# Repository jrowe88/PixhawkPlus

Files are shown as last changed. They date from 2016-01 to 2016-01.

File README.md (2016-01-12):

# Pixhawk Plus #
The [Pixhawk](https://pixhawk.org/choice) and [PX4](http://px4.io/) flight stack are workhorses in DIY drone world.  

Often paired with an OpenTX receiver such as the FrSky, you have a powerful combination.

Pixhawk Plus aims to make better use of this great combination by providing an easy-to-use, modular set of add-ons:

1. Telemetry pass-through from the Pixhawk to your OpenTX receiver.
2. Robust LED indicator lights--multiple arms, multiple programs.
3. Per-cell LIPO voltage monitoring.

## Getting Started ##
- Get the code
- Get the hardware
- Assemble and go!

[See the Wiki for complete instructions](http://#)

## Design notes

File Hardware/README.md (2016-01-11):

# Pixhawk Plus Circuit Boards #
This folder contains Eagle files for corresponding hardware. These boards are not required, but make the packaging neater than soldering a bunch of wires to a Teensy 3.2.

You can order your own, simply wire to the Teensy, or come up with your own creation.  See the Wiki for more options and ideas.

##Primary Board:##
This code and "backpack" are designed to work with [Teensy 3.2](https://www.pjrc.com/store/teensy32.html) development board.  Probably would world with Feather, or Arduino Mini, but I haven't tried that.

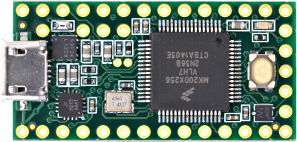
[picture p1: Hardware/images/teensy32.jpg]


##Quadcopter Backpack:##

- Order from [OSHPark.com](https://oshpark.com/shared_projects/TG4BuGQ4) or [contact me](mailto:jim.rowe@gmail.com) for spare boards I may be willing to send you for nominal fee.
- BOM Parts for the Backpack: [From DigiKey](http://www.digikey.com/short/tvfnt3)


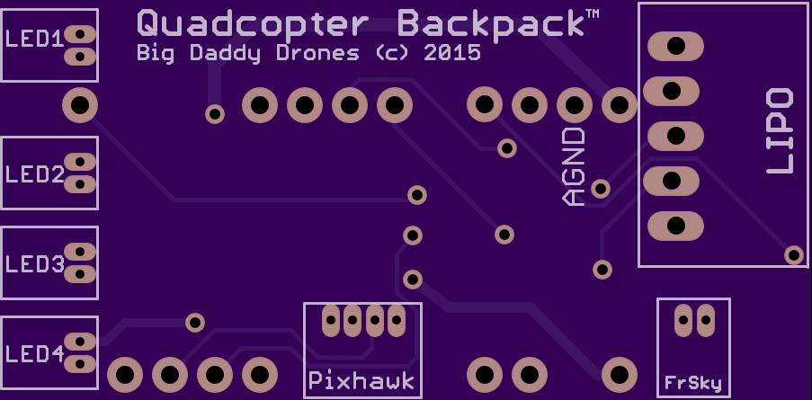
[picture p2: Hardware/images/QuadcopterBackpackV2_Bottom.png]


##LED Leg:##

- Order from [OSHPark.com](https://oshpark.com/shared_projects/HVTKyU7v) or [contact me](mailto:jim.rowe@gmail.com) for spare boards I may be willing to send you for nominal fee.
- You can also use Adafruit NeoPixel or other strips of WS2812b RGB LED lights found from many distributors.

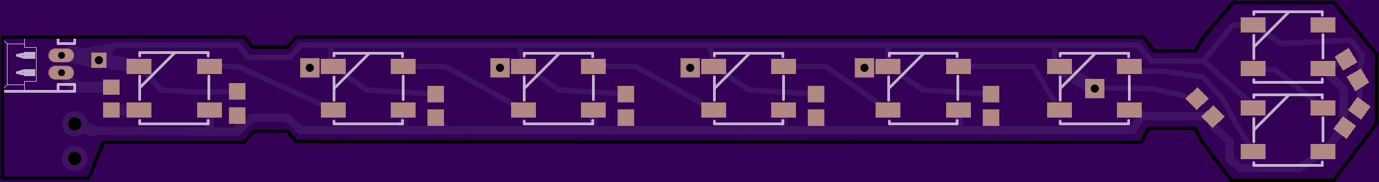
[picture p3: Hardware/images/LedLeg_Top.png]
<a href="https://oshpark.com/shared_projects/HVTKyU7v"><br/></a>
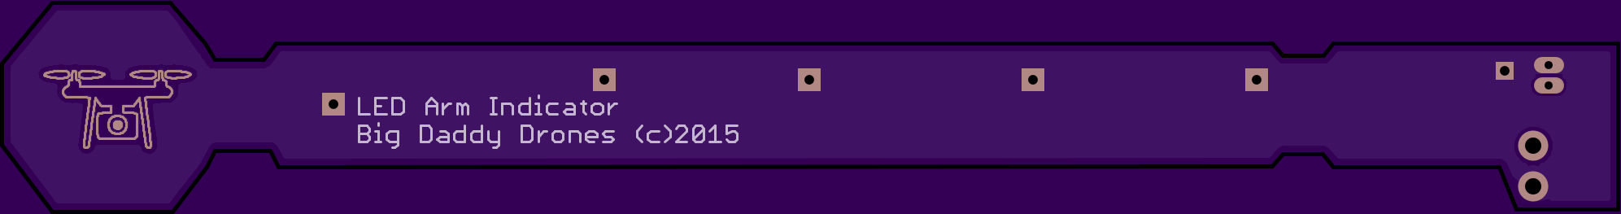
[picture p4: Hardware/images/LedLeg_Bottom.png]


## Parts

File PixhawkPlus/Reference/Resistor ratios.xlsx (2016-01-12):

Voltage Divider Calculator
 |  |  |  |  |  |  |  |  | 4.2 | max per-cell voltage
 | Vin = Vout * H |  |  |  |  |  |  |  | 13 | analog resolution bits
 | H = R2 / (R2 + R1) |  |  |  |  |  |  |  | 8192 | bits sampled
 |  |  |  |  |  |  |  |  | min wattage |  | Examples
Cell | Vin | R1 | R2 | H | Vout | OK? | Ref. Voltage | counts / V | size R1 | size R2 | counts | volts
1 | 4.2 | 993 | 3320 | 0.76977 | 3.233 | Yes | 3.320 | 1899.14213 | 1/10 | 1/10 | 552 | 0.290657551
2 | 8.4 | 1960 | 1240 | 0.38750 | 3.255 | Yes | 3.320 | 956.02786 | 1/10 | 1/10 | 202 | 0.2112909133
3 | 12.6 | 3600 | 1240 | 0.25620 | 3.228 | Yes | 3.320 | 632.08454 | 1/10 | 1/4 | 2662 | 4.21146199
4 | 16.8 | 9090 | 2210 | 0.19558 | 3.286 | Yes | 3.320 | 482.51706 | 1/10 | 1/4 | 8046 | 16.6750581
5 | 21.0 | 6800 | 1240 | 0.15423 | 3.239 | Yes | 3.320 | 380.50860 | 1/10 | 1/2 | 7500 | 19.71046113
6 | 25.2 | 11000 | 1600 | 0.12698 | 3.200 | Yes | 3.320 | 313.29126 | 1/10 | 1/2 | 7000 | 22.34342571
 |  | ^== choose R1 and R2 values to create appropriate ranged Vout
 |  |  |  |  | ^== must be lower than the max reference voltage
 |  |  |  |  |  |  |  |  | ^== choose R1 and R2 that are at least the min wattage listed
Resistor Wattages
0 | 0
0.1 | 1/10
0.125 | 1/8
0.25 | 1/4
0.5 | 1/2

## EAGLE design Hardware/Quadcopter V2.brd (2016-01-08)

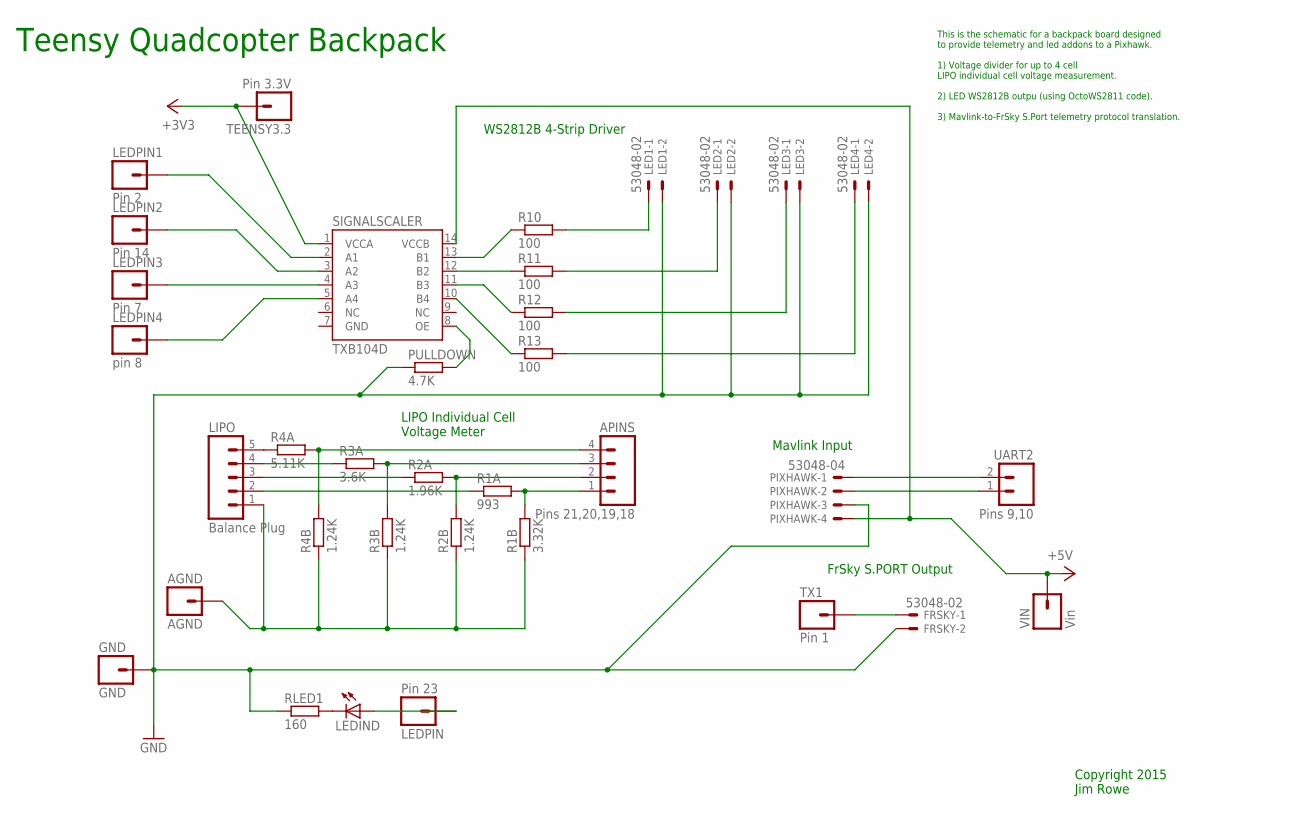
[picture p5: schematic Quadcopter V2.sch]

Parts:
AGND: AGND; 1X01_NO_SILK
APINS: Pins 21,20,19,18; 1X04_NO_SILK_ALL_ROUND
FRSKY: 53048-02
GND: GND; 1X01_NO_SILK
LED1, LED2, LED3, LED4: 53048-02
LEDIND: LEDCHIPLED_0603; CHIPLED_0603
LEDPIN: Pin 23; 1X01_NO_SILK
LEDPIN1: Pin 2; 1X01_NO_SILK
LEDPIN2: Pin 14; 1X01_NO_SILK
LEDPIN3: Pin 7; 1X01_NO_SILK
LEDPIN4: pin 8; 1X01_NO_SILK
LIPO: Balance Plug; 1X05_LOCK_LONGPADS
PIXHAWK: 53048-04
PULLDOWN: 4.7K; R0805
R1A: 993; R0805
R1B: 3.32K; R0805
R2A: 1.96K; R0805
R2B, R3B, R4B: 1.24K; R0805
R3A: 3.6K; R0805
R4A: 5.11K; R0805
R10, R11, R12, R13: 100; R0805
RLED1: 160; R0603
SIGNALSCALER: TXB104D; SOIC(D)-14
TEENSY3.3: Pin 3.3V; 1X01_NO_SILK
TX1: Pin 1; 1X01_NO_SILK
UART2: Pins 9,10; 1X02_NO_SILK
VIN: Vin; 1X01_NO_SILK

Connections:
+3V3: SIGNALSCALER.1 (VCCA), TEENSY3.3.1
+5V: PIXHAWK.4, SIGNALSCALER.14 (VCCB), VIN.1
GND: FRSKY.2, GND.1, LED1.2, LED2.2, LED3.2, LED4.2, PIXHAWK.3, PULLDOWN.1, RLED1.1, SIGNALSCALER.7 (GND)
unnamed: R10.1, SIGNALSCALER.13 (B1)
unnamed: R11.1, SIGNALSCALER.12 (B2)
unnamed: R12.1, SIGNALSCALER.11 (B3)
unnamed: R13.1, SIGNALSCALER.10 (B4)
unnamed: APINS.4, R4A.2, R4B.2
unnamed: APINS.3, R3A.2, R3B.2
unnamed: APINS.2, R2A.2, R2B.2
unnamed: LIPO.5, R4A.1
unnamed: LIPO.4, R3A.1
unnamed: LIPO.3, R2A.1
unnamed: LIPO.2, R1A.1
unnamed: LEDPIN1.1, SIGNALSCALER.2 (A1)
unnamed: LEDPIN2.1, SIGNALSCALER.3 (A2)
unnamed: LEDPIN3.1, SIGNALSCALER.4 (A3)
unnamed: LEDPIN4.1, SIGNALSCALER.5 (A4)
unnamed: AGND.1, LIPO.1, R1B.1, R2B.1, R3B.1, R4B.1
unnamed: APINS.1, R1A.2, R1B.2
unnamed: LED1.1, R10.2
unnamed: LED2.1, R11.2
unnamed: LED3.1, R12.2
unnamed: LED4.1, R13.2
unnamed: PIXHAWK.1, UART2.2
unnamed: PIXHAWK.2, UART2.1
unnamed: LEDIND.C, RLED1.2
unnamed: FRSKY.1, TX1.1
unnamed: PULLDOWN.2, SIGNALSCALER.8 (OE)
unnamed: LEDIND.A, LEDPIN.1

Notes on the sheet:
WS2812B 4-Strip Driver
Teensy Quadcopter Backpack
LIPO Individual Cell Voltage Meter
Mavlink Input
FrSky S.PORT Output
Copyright 2015 Jim Rowe
This is the schematic for a backpack board designed to provide telemetry and led addons to a Pixhawk. 1) Voltage divider for up to 4 cell LIPO individual cell voltage measurement. 2) LED WS2812B outpu (using OctoWS2811 code). 3) Mavlink-to-FrSky S.Port telemetry protocol translation.

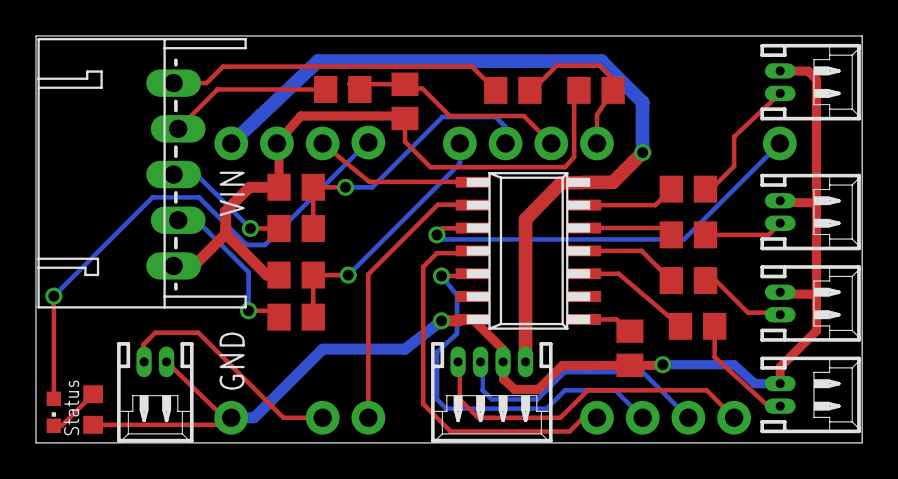
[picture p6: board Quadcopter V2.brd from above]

Board: 2 copper layers, 45.9 x 22.6 mm, 35 parts (0 on the bottom side), 30 nets.

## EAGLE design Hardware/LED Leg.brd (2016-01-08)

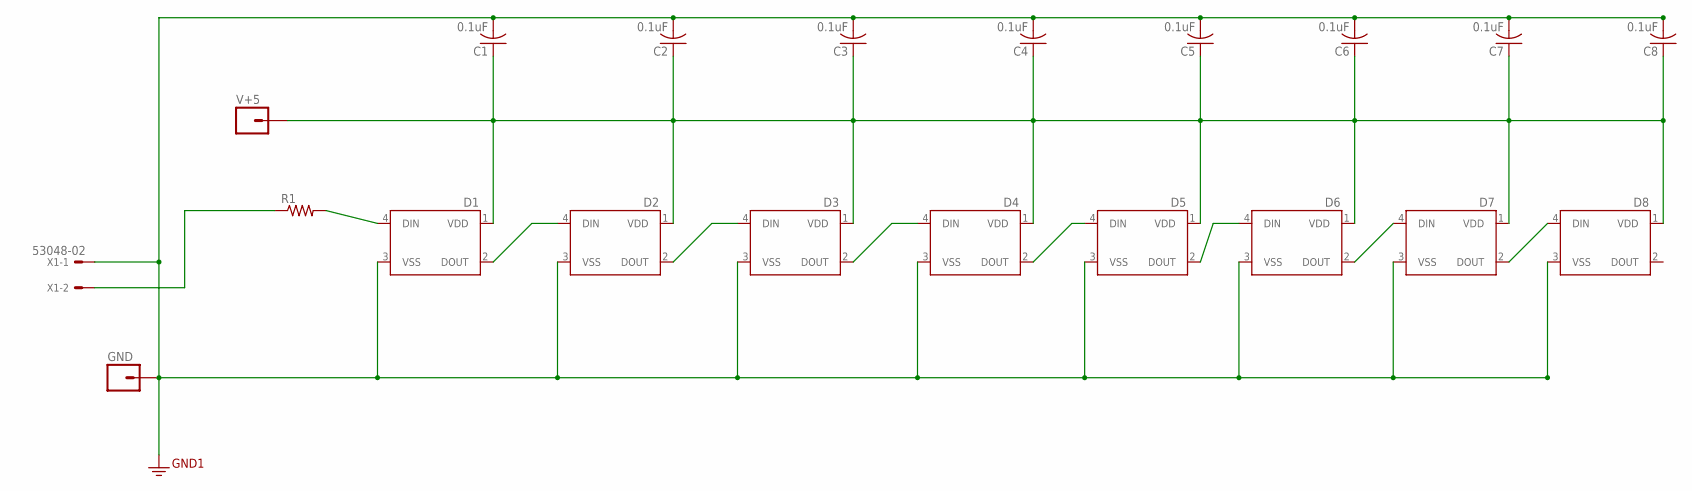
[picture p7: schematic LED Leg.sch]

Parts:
C1, C2, C3, C4, C5, C6, C7, C8: 0.1uF; C0603K
D1, D2, D3, D4, D5, D6, D7, D8: WS2812B
GND: M01NOSILK-KIT; 1X01NS-KIT
R1: R-US_R0603; R0603
V+5: M01NOSILK-KIT; 1X01NS-KIT
X1: 53048-02

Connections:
+5VOLTSUPPLY: C1.1, C2.1, C3.1, C4.1, C5.1, C6.1, C7.1, C8.1, D1.1 (VDD), D2.1 (VDD), D3.1 (VDD), D4.1 (VDD), D5.1 (VDD), D6.1 (VDD), D7.1 (VDD), D8.1 (VDD), V+5.1
GROUND: C1.2, C2.2, C3.2, C4.2, C5.2, C6.2, C7.2, C8.2, D1.3 (VSS), D2.3 (VSS), D3.3 (VSS), D4.3 (VSS), D5.3 (VSS), D6.3 (VSS), D7.3 (VSS), D8.3 (VSS), GND.1, X1.1
LEDSIGNAL: D1.4 (DIN), R1.2
LEDSIGNAL0: R1.1, X1.2
unnamed: D6.2 (DOUT), D7.4 (DIN)
unnamed: D7.2 (DOUT), D8.4 (DIN)
unnamed: D3.2 (DOUT), D4.4 (DIN)
unnamed: D4.2 (DOUT), D5.4 (DIN)
unnamed: D5.2 (DOUT), D6.4 (DIN)
SIGNAL: D1.2 (DOUT), D2.4 (DIN)
SIGNAL1: D2.2 (DOUT), D3.4 (DIN)

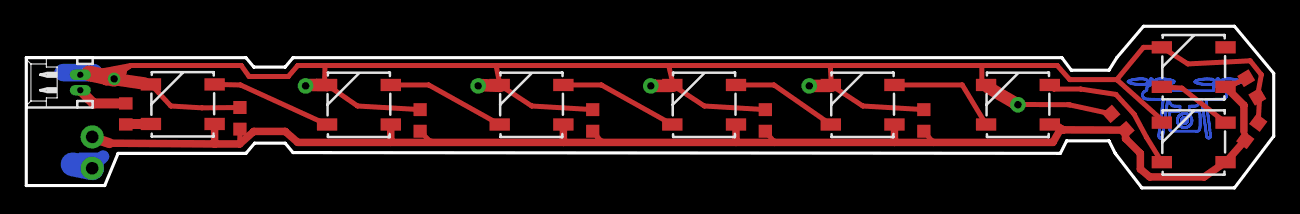
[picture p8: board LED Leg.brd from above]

Board: 2 copper layers, 101.0 x 13.1 mm, 20 parts (0 on the bottom side), 11 nets.

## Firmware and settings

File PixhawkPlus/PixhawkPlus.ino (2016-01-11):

#pragma region Copyright
//This file is part of Pixhawk Plus
//
//Jim Rowe Copyright (c) 2015
//https://github.com/jrowe88/PixhawkPlus
//
//  Original concept and big props to Rolf Blomgren - http://diydrones.com/forum/topics/amp-to-frsky-x8r-sport-converter
//  Adapted and modified from numerous other contributors - https://github.com/Clooney82/MavLink_FrSkySPort/   
//     Alf Pettersson
//     Christian Swahn
//     Luis Vale
//     Michael Wolkstein
//     Jochen Kielkopf
//
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
#pragma endregion

#include <FastLED.h>
#include <OctoWS2811.h>
#include <GCS_MAVLink.h>
#include <FrSkySportSingleWireSerial.h>
#include <FrSkySportSensorAss.h>
#include <FrSkySportSensor.h>
#include <FrSkySportTelemetry.h>
#include <FrSkySportSensorVario.h>
#include <FrSkySportSensorSp2uart.h>
#include <FrSkySportSensorRpm.h>
#include <FrSkySportSensorGps.h>
#include <FrSkySportSensorFuel.h>
#include <FrSkySportSensorFlvss.h>
#include <FrSkySportSensorFas.h>
#include <FrSkySportSensorAcc.h>
#include "MavlinkControl.h"

MavLinkController controller;


void setup()
{			
	controller.Initialize();	
}

void loop()
{
	controller.Process();	
}

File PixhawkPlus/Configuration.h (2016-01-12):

#pragma region Copyright
//This file is part of Pixhawk Plus
//
//Jim Rowe Copyright (c) 2015
//https://github.com/jrowe88/PixhawkPlus
//
//  Original concept and big props to Rolf Blomgren - http://diydrones.com/forum/topics/amp-to-frsky-x8r-sport-converter
//  Adapted and modified from numerous other contributors:
//     Jochen Kielkopf - https://github.com/Clooney82/MavLink_FrSkySPort/   
//     Alf Pettersson
//     Christian Swahn
//     Luis Vale
//     Michael Wolkstein
//     Jochen Kielkopf
//
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
#pragma endregion
#ifndef _CONFIGURATION_h
#define _CONFIGURATION_h

#if defined(ARDUINO) && ARDUINO >= 100
#include "arduino.h"
#else
#include "WProgram.h"
#endif

/*
* *******************************************************
* *** Basic Configuration:                            ***
* *******************************************************
*/
#define debugSerial         Serial
#define debugSerialBaud     57600
#define _MavLinkSerial      Serial2
#define _MavLinkSerialBaud  57600
#define MAVLINK_P_TX        1
#define MAVLINK_P_RX        0
#define LED_BOARD_P         13
#define START               1
#define MSG_RATE            10      // Hertz
#define AP_SYSID            1       // autopilot system id
#define AP_CMPID            1       // autopilot component id
#define MY_SYSID            123     // teensy system id
#define MY_CMPID            123     // teensy component id
#define GB_SYSID            71      // gimbal system id
#define GB_CMPID            67      // gimbal component id

#define AC_VERSION          3.3     // 3.2 backwards compatibility

/*
* *******************************************************
* *** Enable Addons:                                  ***
* *******************************************************
*/
#define USE_SINGLE_CELL_MONITOR                         // Enable/disable single cell monitoring
#define USE_TEENSY_LED_SUPPORT                          // Enable LED-Controller functionality

/*
* *******************************************************
* *** Variables Definitions:                          ***
* *******************************************************
*/
//Single Cell LiPO monitor
#define MAXCELLS 6  //no more than 6 are currently supported
#define ANALOG_SAMPLE_BITS 13

//Voltage ratio for resistor network
//See: 
#define CELL_DIVIDER1_RATIO 0.76977
#define CELL_DIVIDER2_RATIO 0.38750
#define CELL_DIVIDER3_RATIO 0.25620
#define CELL_DIVIDER4_RATIO 0.19558
#define CELL_DIVIDER5_RATIO 0.15423
#define CELL_DIVIDER6_RATIO 0.12698

#define ANALOG1 7
#define ANALOG2 6
#define ANALOG3 5
#define ANALOG4 4
#define ANALOG5 8
#define ANALOG6 9

//LED Control
#define LEDSPERARM 27

/*
* *******************************************************
* *** Debug Options:                                  ***
* *******************************************************
*/
// *** DEBUG MAVLink Messages:
#define DEBUG_APM_MAVLINK_MSGS              // Show all messages received from APM
#define DEBUG_APM_CONNECTION
#define DEBUG_APM_HEARTBEAT                 // MSG #0
#define DEBUG_APM_SYS_STATUS                // MSG #1   - not used -> use: DEBUG_APM_BAT
#define DEBUG_APM_BAT                       // Debug Voltage and Current received from APM
#define DEBUG_APM_GPS_RAW                   // MSG #24
#define DEBUG_APM_RAW_IMU                   // MSG #27  - not used -> use: DEBUG_APM_ACC
#define DEBUG_APM_ACC                       // Debug Accelerometer
#define DEBUG_APM_ATTITUDE                  // MSG #30
#define DEBUG_APM_GLOBAL_POSITION_INT_COV   // MSG #63  - planned - currently not implemented - not supported by APM
#define DEBUG_APM_RC_CHANNELS               // MSG #65
#define DEBUG_APM_VFR_HUD                   // MSG #74
#define DEBUG_APM_STATUSTEXT                // MSG #254 -
#define DEBUG_APM_PARSE_STATUSTEXT
#define DEBUG_GIMBAL_HEARTBEAT
//#define DEBUG_PROCESSING_STATE

// *** DEBUG FrSkySPort Telemetry:
#define DEBUG_FrSkySportTelemetry
#define DEBUG_FrSkySportTelemetry_FAS
#define DEBUG_FrSkySportTelemetry_FLVSS
#define DEBUG_FrSkySportTelemetry_GPS
#define DEBUG_FrSkySportTelemetry_RPM
#define DEBUG_FrSkySportTelemetry_A3A4
#define DEBUG_FrSkySportTelemetry_VARIO
#define DEBUG_FrSkySportTelemetry_ACC
#define DEBUG_FrSkySportTelemetry_FLIGHTMODE

// *** DEBUG other things:
#define DEBUG_AVERAGE_VOLTAGE
#define DEBUG_LIPO_SINGLE_CELL_MONITOR 1  //SET TO 1 TO TURN ON

#endif

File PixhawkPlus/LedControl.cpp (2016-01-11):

#pragma region Copyright
//This file is part of Pixhawk Plus
//
//Jim Rowe Copyright (c) 2015
//https://github.com/jrowe88/PixhawkPlus
//
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
#pragma endregion

#include "LedControl.h"

//Some standard color definitions
static const int C_DISARMED = CRGB::Red;
static const int C_ARMED = CRGB::DarkCyan;
static const int C_NOGPS = CRGB::Orange;
static const int C_GPSSEEK = CRGB::Green;
static const int C_FIX2D = CRGB::LawnGreen;
static const int C_FIX3D = CRGB::Green;
static const int C_BLACK = CRGB::Black;

//High speed WS2812B driver configuration
DMAMEM int _ledDisplayMemory[LEDSPERARM * 6];
DMAMEM int _ledDrawingMemory[LEDSPERARM * 6];

/*
	Global variables used:
		ap_voltage_battery
		ap_cell_count
		ap_fixtype  // 0 = No GPS, 1 =No Fix, 2 = 2D Fix, 3 = 3D Fix, 4 = DGPS, 5 = RTK
		ap_sat_visible
*/

const float LedControl::MS_PER_FRAME = 31.25;  // = ~32fps, so our 64-bit periods will be two seconds

LedControl::LedControl(MAVLinkData *messages) :
	_ledDriver(LEDS_PER_ARM, _ledDisplayMemory, _ledDrawingMemory, CONFIG)
{
	_messages = messages;
			
	_ch.CreateSinePulse(FRAMES_PER_LOOP, _sinPulse, 32);
	_ch.CreateSinePulse(FRAMES_PER_LOOP, _sinDoublePulse, 16);
	_ch.CreateSinePulse(FRAMES_PER_LOOP, _sinQuadPulse, 8);
	_ch.CreateLinearRamp(FRAMES_PER_LOOP, _rampSingle, 64);
	_ch.CreateLinearRamp(FRAMES_PER_LOOP, _rampDouble, 32);
	_ch.CreateLinearRamp(FRAMES_PER_LOOP, _rampQuad, 16);
	_ch.CreateRainbow(FRAMES_PER_LOOP, _rainbow);
	_ch.CreateJPLRedBlue(FRAMES_PER_LOOP, _jetRB, 1);
	_ch.CreateJPLRedBlue(FRAMES_PER_LOOP, _jetBR, 0);
}

LedControl::~LedControl()
{	
}

//Called once to initialize
void LedControl::Initialize()
{
	_ledDriver.begin();	
	AllOff();
	_ledDriver.show();	
}

//Called once in the main Processing Loop.
// This is a constant frame rate loop that will excute once per frame, which is approximately
//  at 30 frames per second.  Assumption is that calculations are trivial enough that there are
//  plenty of tics to complete the work within a frame.  If not, it will just run at a slower
//  frame rate and blink patterns and functions may be erratic.
void LedControl::Process()
{
	//Only process this once per frame
	_frame = millis() / MS_PER_FRAME;
	
	if (_frame != _lastFrame)
	{						
		//Armed/Disarmed Status
		///*SetPixelsSolid(1, C_ARMED);
		//SetPixelsSolid(3, C_ARMED);
		//SetPixelsSolid(5, C_ARMED);
		//*/SetPixelsSolid(7, C_ARMED);		

		//GPS Fix		
		SetGPSLights(Fix2D);

		//Nav Lights


		//Breaking


		//Mode


		//Swith Response


		//Set all the pixels and show them
		ShowFrame();	
		_lastFrame = _frame;
	}
}

void LedControl::NoMavLink()
{
}

void LedControl::AllOff()
{
	for (int i = 0; i < LEDS_PER_ARM * NUM_ARMS; i++)
	{
		_ledDriver.setPixel(i, 0);
	}
}

void LedControl::SetPixelsSolid(uint32_t pixel, int color)
{	
	SetPixelsBlinkPattern(pixel, color, _ch.ALL_FRAMES);
}

//Blinks a pixel based on the binary pattern
void LedControl::SetPixelsBlinkPattern(uint32_t pixel, int color, uint64_t pattern)
{	
	for (size_t f = 0; f < FRAMES_PER_LOOP; f++)
	{
		int colordisp = color * (pattern >> f & 0x1);
		for (size_t i = 0; i < NUM_ARMS; i++)
		{
			_display[f][i * LEDS_PER_ARM + pixel] = colordisp;
		}
	}
}

//Sets color pattern.  Expects a int[FRAMES_PER_LOOP] sized array
void LedControl::SetPixelsColorPattern(uint32_t pixel, int *colorPattern, int shift = 0)
{
	for (size_t f = 0; f < FRAMES_PER_LOOP; f++)
	{		
		for (size_t i = 0; i < NUM_ARMS; i++)
		{
			int c = (f + shift) % FRAMES_PER_LOOP;
			_display[f][i * LEDS_PER_ARM + pixel] = colorPattern[c];
		}
	}
}

//Blinks a pixel baesd on a user supplied wave with 0-to-1 scale factor.
void LedControl::SetPixelsUserFcn(uint32_t pixel, int color, uint8_t *intensityWave)
{
	for (size_t f = 0; f < FRAMES_PER_LOOP; f++)
	{		
		int c = _ch.Dim(color, intensityWave[f]);
		for (size_t i = 0; i < NUM_ARMS; i++)
		{			
			_display[f][i * LEDS_PER_ARM + pixel] = c;
		}
	}
}

void LedControl::SetPixelBlink(uint64_t pattern, uint32_t arm, uint32_t pixel, int color)
{
	for (size_t f = 0; f < FRAMES_PER_LOOP; f++)
	{
		int colordisp = color * (pattern >> f & 0x1);
		_display[f][arm * LEDS_PER_ARM + pixel] = colordisp;
	}
}

void LedControl::SetGPSLights(uint8_t gpsStatus)
{
	switch(gpsStatus)
	{
	case NoGPS: 
		SetPixelsBlinkPattern(0, C_NOGPS, _ch.BLINK_MEDIUM_A);
		SetPixelsBlinkPattern(2, C_NOGPS, _ch.BLINK_MEDIUM_A);
		SetPixelsBlinkPattern(4, C_NOGPS, _ch.BLINK_MEDIUM_A);
		SetPixelsBlinkPattern(6, C_NOGPS, _ch.BLINK_MEDIUM_A);
		break;
	case NoFix:
		//GpsSeeking(0);
		for (size_t i = 0; i < 8; i++)
		{
			SetPixelsSolid(i, 0x808080);
		}		
		break;
	case Fix2D:
		for (size_t i = 0; i < LEDSPERARM; i++)
		{
			SetPixelsColorPattern(i, _rainbow);
			//SetPixelsColorPattern(i, _rainbow, 255 * i/LEDSPERARM );
		}		
		break;
	case Fix3D:
		SetPixelsBlinkPattern(6, C_FIX3D, _ch.BLINK_FAST_A);
		break;
	default: break;
	}

}

void LedControl::GpsSeeking(uint32_t numFound)
{
	CRGB c = C_GPSSEEK;
	int armOffset = 0;
	float dim = .45;

	for (size_t i = 0; i < LEDS_PER_ARM - 1; i++)
	{		
		for (size_t j = 0; j < LEDS_PER_ARM - 1; j++)
		{
			if (j <= i)
			{
				_ledDriver.setPixel(armOffset + j, c.r * dim, c.g * dim, c.b * dim);
			}
		}
	}
}

//Sets the pixels for the current frame and render the pixels.
void LedControl::ShowFrame()
{
	int frameSequence = _frame % FRAMES_PER_LOOP;
	for (size_t i = 0; i < _numLeds; i++)
	{
		_ledDriver.setPixel(i, _display[frameSequence][i]);
	}
	_ledDriver.show();	
}

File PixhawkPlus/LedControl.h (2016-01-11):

#pragma region Copyright
//This file is part of Pixhawk Plus
//
//Jim Rowe Copyright (c) 2015
//https://github.com/jrowe88/PixhawkPlus
//
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
#pragma endregion

#ifndef _LEDCONTROL_h
#define _LEDCONTROL_h

#include <stdint.h>
#include "Configuration.h"
#include "MAVLinkData.h"
#include "LedColorHelpers.h"
#include <OctoWS2811.h>


/// <summary>
/// Control code for the LedLights.
/// </summary>
class LedControl
{
public:
	LedControl(MAVLinkData *messages);
	~LedControl();
	void Initialize();
	void Process();
	void NoMavLink();
	static const uint32_t LEDS_PER_ARM = LEDSPERARM;
	
	enum FLIGHTMODE : int
	{
		Disarmed = 0x1,
		Armed = 0x2,
		Standard = 0x4,
		Stabilize = 0x8,
		Altitude = 0x10,
		Loiter = 0x20,
		Return = 0x40
	};

	enum GPSFIX : uint8_t
	{
		NoGPS = 0,
		NoFix = 1,
		Fix2D = 2,
		Fix3D = 3
	};

private:
	
	MAVLinkData *_messages;
	OctoWS2811 _ledDriver;
	static const LedColorHelpers _ch;

	static const uint8_t CONFIG = WS2811_GRB | WS2811_800kHz;
	static const int NUM_ARMS = 1;	
	uint32_t _frame = 0, _lastFrame = 0;
	static const uint8_t FRAMES_PER_LOOP = 64;     //frame loop length
	static const float MS_PER_FRAME;
	static const uint32_t _numLeds = LEDS_PER_ARM * NUM_ARMS;
	int _display[FRAMES_PER_LOOP][_numLeds];       //array of 24-bit colors, per-frame; per-pixe
	
	//Some basic intensity waves
	uint8_t _sinPulse[FRAMES_PER_LOOP];
	uint8_t _sinDoublePulse[FRAMES_PER_LOOP];
	uint8_t _sinQuadPulse[FRAMES_PER_LOOP];
	uint8_t _rampSingle[FRAMES_PER_LOOP];
	uint8_t _rampDouble[FRAMES_PER_LOOP];
	uint8_t _rampQuad[FRAMES_PER_LOOP];
	int _rainbow[FRAMES_PER_LOOP];
	int _jetRB[FRAMES_PER_LOOP];
	int _jetBR[FRAMES_PER_LOOP];

	//Methods
	void SetPixelsSolid(uint32_t pixel, int color);
	void SetPixelsBlinkPattern(uint32_t pixel, int color, uint64_t pattern);
	void SetPixelsColorPattern(uint32_t pixel, int *colorPattern, int shift);
	void SetPixelsUserFcn(uint32_t pixel, int color, uint8_t *intensityWave);
	void SetPixelBlink(uint64_t pattern, uint32_t arm, uint32_t pixel, int color);
	void SetGPSLights(uint8_t gpsStatus);
	void GpsSeeking(uint32_t found);
	void ShowFrame();
	void AllOff();
};


#endif

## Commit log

2016-01-08 initial push
    initial push - beta version
    [Configuration.h]
2016-01-08 Added board files
    [LED Leg.brd, LED Leg.sch, Quadcopter V2.brd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]
2016-01-11 lipo monitor and smoothing updates
    [Configuration.h]
2016-01-12 updates and reference information
    [Configuration.h, Resistor ratios.xlsx]

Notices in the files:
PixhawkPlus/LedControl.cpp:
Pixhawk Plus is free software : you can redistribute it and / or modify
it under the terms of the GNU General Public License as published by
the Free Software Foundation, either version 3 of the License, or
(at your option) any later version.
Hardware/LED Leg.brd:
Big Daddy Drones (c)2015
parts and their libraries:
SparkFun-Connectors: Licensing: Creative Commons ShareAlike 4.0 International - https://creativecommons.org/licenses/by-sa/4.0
